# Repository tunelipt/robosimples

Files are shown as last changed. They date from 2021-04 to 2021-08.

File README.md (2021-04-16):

# robosimples
Sistema para movimentação do Robô do Túnel de Movimento usando OEM750

A placa do robô do túnel de vento queimou. O sistema usa indexadores OEM-750 para controlar os motores de passo. Esta é uma tentativa simples de controlar os motores de passo. A idéia é, mais para frente fazer um sistema completo que consiga gerar movimentos completos com sensores de fim de curso, etc.

Por enquanto isso aqui é simplesmente um "laboratório" para explorar o problema. Este "laboratório tem as seguintes componentes:

 - Placa eletrônica para 3 eixos controlados por ESP32 Devkit v1 com 30 pinos. Projeto KICAD está na pasta robosimples
 - Programa arduino e C++ que vai na placa localizado na pasta roboesp32
 - Programa + servidor XML-RPC em python
 - Interfaces para outras linguagens de programação.

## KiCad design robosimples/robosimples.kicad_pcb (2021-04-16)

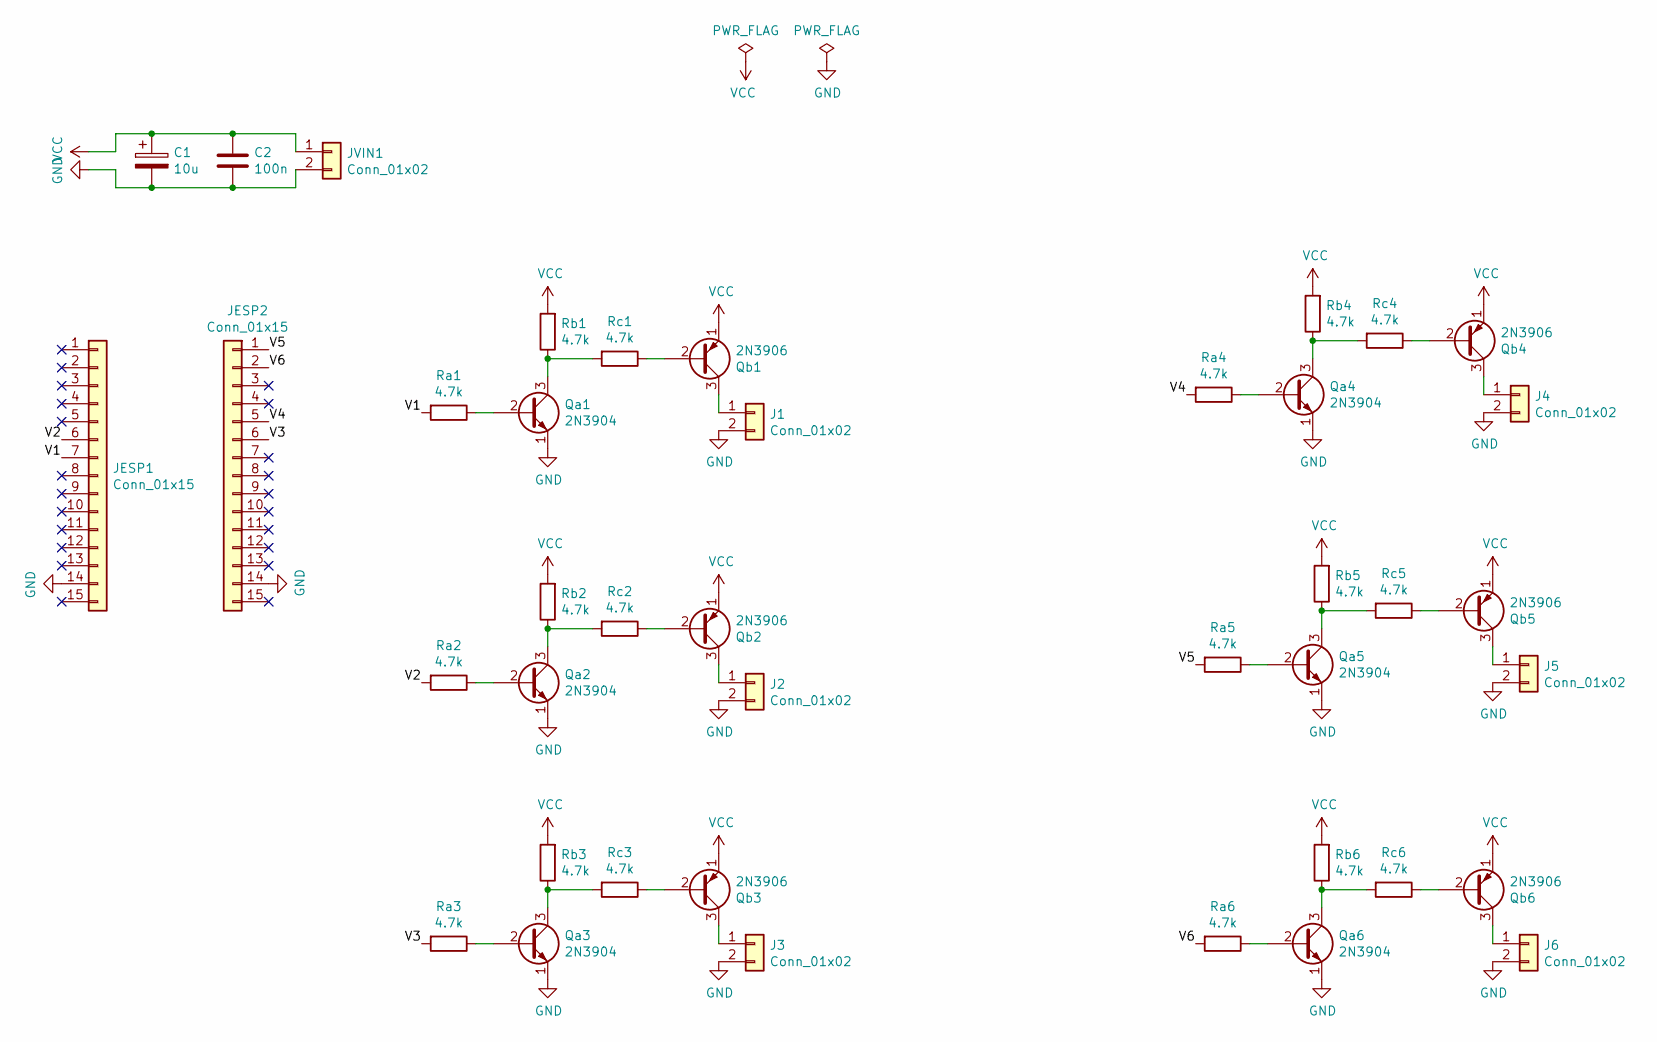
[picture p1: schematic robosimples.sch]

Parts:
C1: 10u; CP_Radial_D5.0mm_P2.50mm
C2: 100n; C_Rect_L7.2mm_W3.5mm_P5.00mm_FKS2_FKP2_MKS2_MKP2
J1, J2, J3, J4, J5, J6: Conn_01x02; TerminalBlock_bornier-2_P5.08mm
JESP1, JESP2: Conn_01x15; PinSocket_1x15_P2.54mm_Vertical
JVIN1: Conn_01x02; TerminalBlock_bornier-2_P5.08mm
Qa1, Qa2, Qa3, Qa4, Qa5, Qa6: 2N3904; TO-92_Inline_Wide
Qb1, Qb2, Qb3, Qb4, Qb5, Qb6: 2N3906; TO-92_Inline_Wide
Ra1, Ra2, Ra3, Ra4, Ra5, Ra6: 4.7k; R_Axial_DIN0207_L6.3mm_D2.5mm_P10.16mm_Horizontal
Rb1, Rb2, Rb3, Rb4, Rb5, Rb6: 4.7k; R_Axial_DIN0207_L6.3mm_D2.5mm_P10.16mm_Horizontal
Rc1, Rc2, Rc3, Rc4, Rc5, Rc6: 4.7k; R_Axial_DIN0207_L6.3mm_D2.5mm_P10.16mm_Horizontal

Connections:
/V1: JESP1.7, Ra1.2
/V2: JESP1.6, Ra2.2
/V3: JESP2.6, Ra3.2
/V4: JESP2.5, Ra4.2
/V5: JESP2.1, Ra5.2
/V6: JESP2.2, Ra6.2
GND: C1.2, C2.2, J1.2, J2.2, J3.2, J4.2, J5.2, J6.2, JESP1.14, JESP2.14, JVIN1.2, Qa1.1 (E), Qa2.1 (E), Qa3.1 (E), Qa4.1 (E), Qa5.1 (E), Qa6.1 (E)
unnamed: J1.1, Qb1.3 (C)
unnamed: J2.1, Qb2.3 (C)
unnamed: J3.1, Qb3.3 (C)
unnamed: J4.1, Qb4.3 (C)
unnamed: J5.1, Qb5.3 (C)
unnamed: J6.1, Qb6.3 (C)
unnamed: Qa1.2 (B), Ra1.1
unnamed: Qa1.3 (C), Rb1.1, Rc1.2
unnamed: Qa2.2 (B), Ra2.1
unnamed: Qa2.3 (C), Rb2.1, Rc2.2
unnamed: Qa3.2 (B), Ra3.1
unnamed: Qa3.3 (C), Rb3.1, Rc3.2
unnamed: Qa4.2 (B), Ra4.1
unnamed: Qa4.3 (C), Rb4.1, Rc4.2
unnamed: Qa5.2 (B), Ra5.1
unnamed: Qa5.3 (C), Rb5.1, Rc5.2
unnamed: Qa6.2 (B), Ra6.1
unnamed: Qa6.3 (C), Rb6.1, Rc6.2
unnamed: Qb1.2 (B), Rc1.1
unnamed: Qb2.2 (B), Rc2.1
unnamed: Qb3.2 (B), Rc3.1
unnamed: Qb4.2 (B), Rc4.1
unnamed: Qb5.2 (B), Rc5.1
unnamed: Qb6.2 (B), Rc6.1
VCC: C1.1, C2.1, JVIN1.1, Qb1.1 (E), Qb2.1 (E), Qb3.1 (E), Qb4.1 (E), Qb5.1 (E), Qb6.1 (E), Rb1.2, Rb2.2, Rb3.2, Rb4.2, Rb5.2, Rb6.2

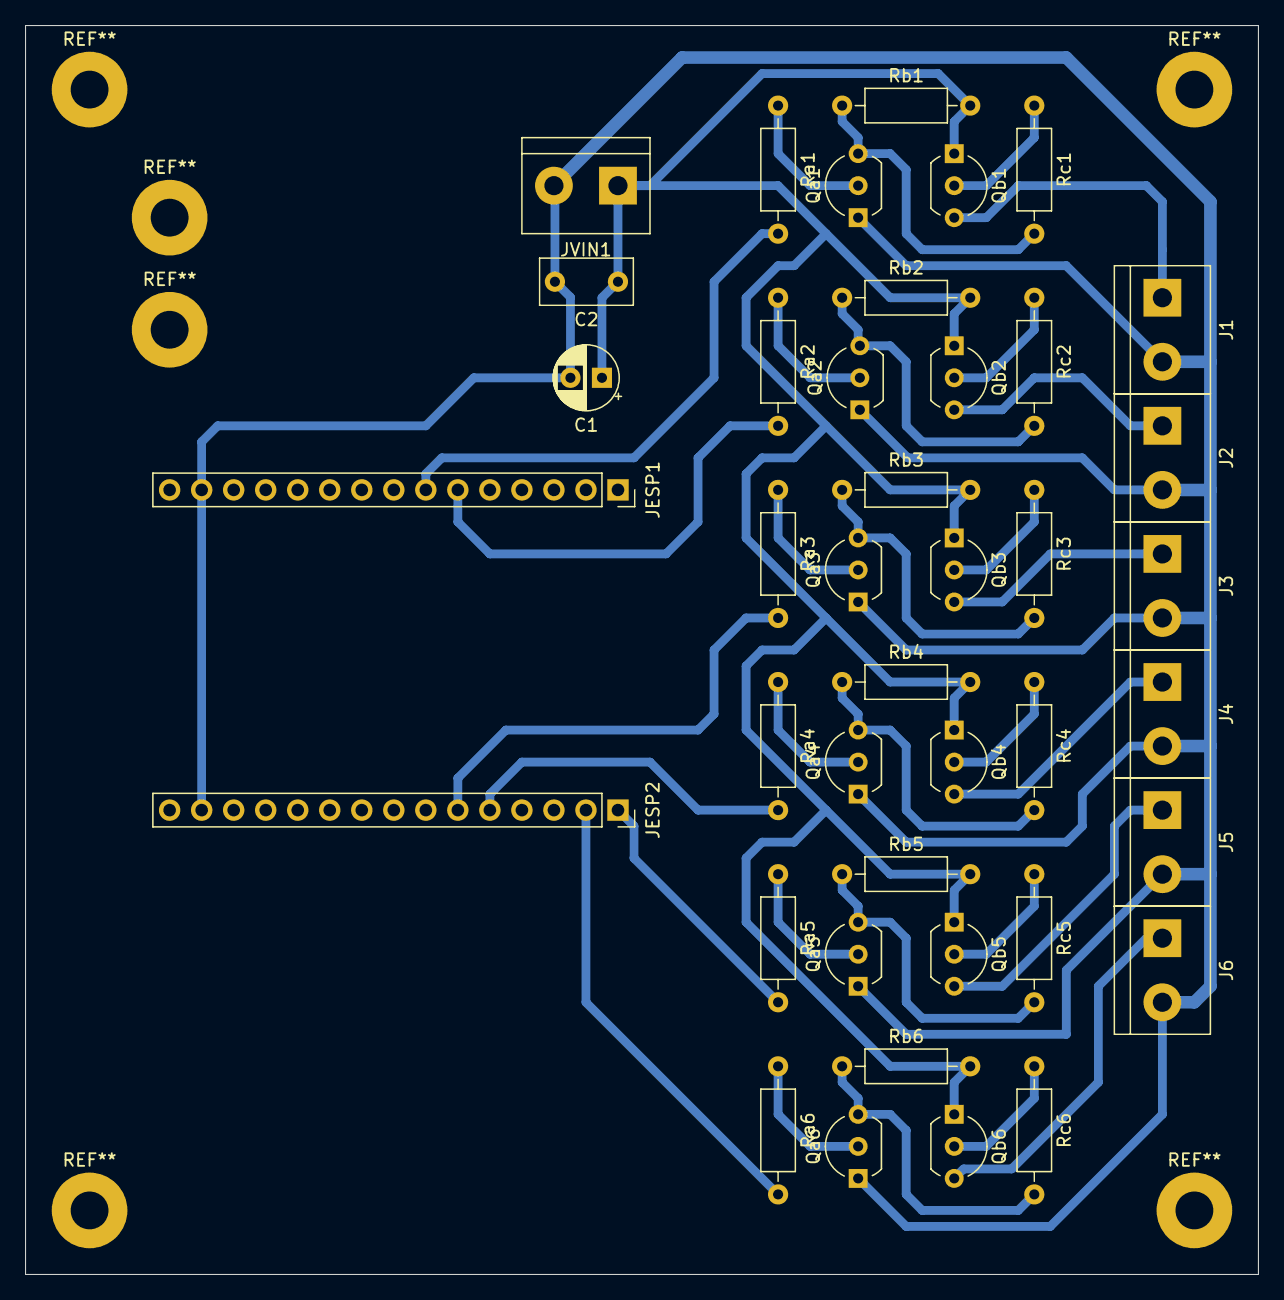
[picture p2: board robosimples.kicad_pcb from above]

Board: 2 copper layers, 97.8 x 99.1 mm, 41 parts (0 on the bottom side), 32 nets.

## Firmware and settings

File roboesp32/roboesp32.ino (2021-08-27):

/**
 * Basic ADC reading example.
 * - connects to ADC
 * - reads value from channel
 * - converts value to analog voltage
 */

#include "oem750.h"


#define PINO1        33   // Pino saída 1
#define PINO2        32   // Saída 2
#define PINO3        19   // Pino saida 3
#define PINO4        21   // Saída 4
#define PINO5        23   // Saída 5
#define PINO6        22   // Saída 6

const uint8_t pinos[] = {PINO1, PINO2, PINO3, PINO4, PINO5, PINO6};
const int NPINOS = 6;


            
  

MoveAxis Z(PINO1, PINO2, 39500, 19750); // Vel 20 mm/s
MoveAxis Y(PINO3, PINO4, 14070, 7035); // Vel 30 mm/s
MoveAxis X(PINO5, PINO6, 42150, 21075); // Vel 30 mm/s

MoveAxis *axes[] = {&Z, &Y, &X}; 
void setup() {

  
  Serial.begin(9600);
  X.set_position(0);
  delay(1000);
       
}

// Check if the string is a valid + or  integer
int checkstr(String s)
{
  int i1 = 0;
  char c = s[0];
  if (c != '+' && c != '-' && (c < '0' || c > '9') )
  {
    return 0;
  }
  
  for (int i = 1; i < s.length(); ++i)
  { 
    c = s[i];
    if (c < '0' || c > '9') return 0;
  }
  return 1;
}

/*
 # Communication protocol

 The command has the following structure, using regular expressions:
 
  * `[PMRAV][0-2](!|?)[+-]?[0-9]+`

 The following commands are possible
  * `P`: get/set postion
  * `M`: move to a position
  * `R`: Relative motion
  * `A`: Acceleration and deceleration ramp (pulses/s^2)
  * `V`: Terminal velocity (pulses/s)

 Each command is applied to an axis (0,1 or 2) and the command asks for 
 something(`?`) or sets something (`!`).
 
 A few examples will show better how this works:
   * `P0?` Get the position of axis 0
   * `M0!123` Move axis 0 to position 123
   * `R0!10` Move axis 0 10 units forward with respect to present position
   * `P1?` Get the position of axis 1
   * `M1!123` Move axis 1 to position 123
   * `R1!10` Move axis 1 10 units forward with respect to present position
   * `A2?` Read the acceleration of axis 2
   * `A2!1000` Set the acceleration of axis 2 to 1000 pulses/s^2
   * `V1?` Get the velocity of axis 1
   * `V2!12000` Set the velocity of axis 2 to 12000 pulses/s

  The functionality is basic but in the future the system should be able to move
  the 3 axes in lines simultaneously. Some emergency stop is important and the 
  ability to detect end of line sensors must be added.
  
 */
void loop() {
  char cmd;
  int query = 0;
  int axis = -1;
  String s;
  int len = 0;
  int val = 0;
  int resp = 0;
    
  if (Serial.available() > 0)
  {
    delay(20);  // Wait a bit to make sure to receiveto receive an entire line! 
    // Read the command character
    cmd = Serial.read();
    
    // For now, only move ('M') or relative move ('R') is accepted
    if (cmd != 'M' && cmd != 'R' && cmd != 'P' && cmd != 'V' && cmd != 'A')
    {
      Serial.print("ERR - Unknown command! --> ");
      Serial.println(cmd);
      
      delay(50);
      s = Serial.readString();
      return;
      
    }
    delay(20);
    s = Serial.readStringUntil('\n'); 
    s.trim();
    len = s.length();
    // Read the axis character
    if (s[0] == '0')
      axis = 0;
    else if (s[0] == '1')
      axis = 1;
    else if (s[0] == '2')
      axis = 2;
    else{
      Serial.print("ERR - Unavailable axis. It should be 1,2 or 3. Received: ");
      Serial.println(s[1]); 
      
      delay(50);
      s = Serial.readString();
      return;
    }

    // Read the query character
    if (s[1] == '!')
      query = 0;
    else if (s[1] == '?')
      query = 1;
    else{
      Serial.print("ERR - Unknown option. Expected ! or ? received: ");
      Serial.println(s[1]);
      
      delay(50);
      s = Serial.readString();
      return;
    }


    // If a query, return a value:
    if (query == 1)
    {
      if (cmd == 'A')
      {
        Serial.print("A");
        Serial.print(axis);
        Serial.print("?");
        Serial.println(axes[axis]->get_acceleration());
        return;
      }
      else if (cmd == 'V')
      {
        Serial.print("V");
        Serial.print(axis);
        Serial.print("?");
        Serial.println(axes[axis]->get_velocity());
        return;
      }
      else if (cmd == 'P')
      {
        Serial.print("P");
        Serial.print(axis);
        Serial.print("?");
        Serial.println(axes[axis]->get_position());
        return;
      }
      else
      {
        // It doesn't make much sense
        Serial.print(cmd);
        Serial.print(axis);
        Serial.println("?0");
      }
    }
    else
    {
      // Read the integer value:
      String snum = s.substring(2);
      if (!checkstr(snum)){
        Serial.print("ERR - The argument should be an integer. Received ");
        Serial.println(snum); 
      
        delay(50);
        s = Serial.readString();
        return;
      }
      int val = snum.toInt();
      int rval = 0;
      if (cmd=='A'){
         rval = axes[axis]->set_acceleration(val);
      }else if (cmd=='V'){
        rval = axes[axis]->set_velocity(val);
      }else if (cmd=='P'){
        rval = axes[axis]->set_position(val);
      }else if (cmd=='R'){
        rval = axes[axis]->rmove(val);
      }else if (cmd=='M'){
        rval = axes[axis]->move(val);
      }else{
        Serial.println("ERR - Don't know how we got here!");
          
        delay(50);
        s = Serial.readString();
        return;
      }
      // Build the response
      Serial.print(cmd);
      Serial.print(axis);
      Serial.print("!");
      Serial.println(rval);    
      return;
    }
  }

}     
 

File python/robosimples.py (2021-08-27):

import serial
import time
import argparse

from xmlrpc.server import SimpleXMLRPCServer

class ESPRobo(object):
    
    
    def __init__(self, dev='/dev/ttyUSB0', mmps=[-1975, -469, -1405],
                 axes=dict(x=2, y=1, z=0)):
        self.mmps = mmps  # mm per step
        self.s = serial.Serial(dev, 9600)
        self.dev = dev
        self.axes = axes
    def close(self):
        self.s.close()
        return None

    def iaxis(self, ax=0):
        if isinstance(ax, str):
            iax = self.axes[ax.lower()]
        elif isinstance(ax, int):
            iax = ax
        else:
            raise ValueError('{} is an invalid axis specifier'.format(ax))
        if not (0 <= iax <= 2):
            raise ValueError('{} is an invalid axis specifier'.format(ax))

        return iax

        
    def move(self, mm=0, ax=0, r=True):
        iax = self.iaxis(ax)
        npulses = int(mm * self.mmps[iax])
        cmdchar = 'R' if r else 'M'
        cmd = '{}{}!{}'.format(cmdchar, iax, npulses).encode('ASCII')
        self.s.write(cmd)
        time.sleep(0.5)
        while True:
            if self.s.in_waiting > 0:
                break
            time.sleep(0.5)
            
        time.sleep(0.5)

        b = self.s.readline()
        r = b.decode('ASCII')
        return r
    def moveX(self, mm):
        return self.move(mm, self.axes['x'], r=False)
    def moveY(self, mm):
        return self.move(mm, self.axes['y'], r=False)
    def moveZ(self, mm):
        return self.move(mm, self.axes['z'], r=False)

    def rmoveX(self, mm):
        return self.move(mm, self.axes['x'], r=True)
    def rmoveY(self, mm):
        return self.move(mm, self.axes['y'], r=True)
    def rmoveZ(self, mm):
        return self.move(mm, self.axes['z'], r=True)
    
    def position(self, ax=None, pulses=False):
        if ax is None:
            # read each axis
            x = self.position(self.axes['x'], pulses)
            y = self.position(self.axes['y'], pulses)
            z = self.position(self.axes['z'], pulses)
            return(dict(x=x, y=y, z=z))
        else:
            iax = self.iaxis(ax)
            cmd = 'P{}?'.format(iax).encode('ASCII')
            self.s.write(cmd)
            time.sleep(0.1)
            r = self.s.readline().decode('ASCII')

            pos = int(r[3:])

            if pulses:
                return pos
            else:
                return pos / self.mmps[iax]


    def set_reference(self, ax, mm=0, pulses=False):
        iax = self.iaxis(ax)

        if pulses:
            nsteps = mm
        else:
            nsteps = int(mm * self.mmps[iax])

        cmd = 'P{}!{}'.format(iax, nsteps).encode('ASCII')
        self.s.write(cmd)
        self.s.flush()
        time.sleep(0.2)
        return self.s.readline()
    
    

        
def start_server(ip='localhost', port=9543, comport='/dev/ttyUSB0'):
    dev = ESPRobo(comport)
    print("Starting XML-RPC server for Z mover")
    print("IP: {}, port: {}".format(ip, port))
    server = SimpleXMLRPCServer((ip, port), allow_none=True)
    server.register_instance(dev)
    server.serve_forever()


if __name__ == "__main__":
    print("Creating interface ...")
    parser = argparse.ArgumentParser(description="ESPDaq server")
    parser.add_argument("-i", "--ip", help="IP address of the XML-RPC server", default="localhost")
    parser.add_argument("-p", "--port", help="XML-RPC server port", default=9541, type=int)
    parser.add_argument("-s", "--comport", help="Serial port to be used", default="/dev/ttyUSB0")

    args = parser.parse_args()
    start_server(args.ip, args.port, args.comport)
    

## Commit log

2021-04-16 Commit inicial da placa do robo simples
    Esta é uma placa simples só para ter a funcionalidade básica e permitir estudar o problema.
    [robosimples.kicad_pcb, robosimples.sch]
2021-08-02 Acertando os valores para o eixo x
2021-08-27 Três eixos podem ser usados!
    Ainfa mexendo na parte do esp32. Preciso ainda implementar
    a interface Python.
2021-08-27 The esp board can handle 3 axes and a better protocol was implemented
    The functionality is very simple and should be improved upon. But it
    satisfies our minimal needs. Still need to implement the python interface.
2021-08-27 Corrected small bugs
    The code appears to be working!
    [robosimples.py]
